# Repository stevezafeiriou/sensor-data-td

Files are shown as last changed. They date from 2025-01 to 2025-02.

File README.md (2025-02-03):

# SensorDataTD: Real-Time Sensor Data Transfer System



The **SensorDataTD** project is a complete solution for real-time accelerometer data collection, processing, and transmission. It includes both hardware and software components, along with a 3D-printable case design.

You can find the complete tutorial at this link: [Sensor Data to TouchDesigner](#) _(Link to be added)_.

## Project Overview

This project comprises four main components:

1. **ESP32 Firmware**: Collects sensor data from an MPU6050 accelerometer, processes it, and transmits it via WebSocket.
2. **Server**: A Node.js WebSocket server to handle incoming sensor data and broadcast it to connected clients.
3. **React App**: A real-time 3D visualization of sensor data using React and Three.js.
4. **3D-Printed Case**: A custom enclosure for the LilyGo T-Display S3 and MPU6050 hardware.

## Folder Structure

- **`SensorDataTD/`**
  - **`SensorDataTD/`**: Contains the ESP32 firmware and related code.
    - [Read the ESP32 Firmware Documentation](./SensorDataTD/README.md)
  - **`models/`**: Contains `.stl` files and 3D-printing instructions for the project case.
  - **`server/`**: Contains the WebSocket server code in Node.js.
    - [Read the Server Documentation](./server/README.md)
  - **`react-app/`**: A React application for real-time visualization of sensor data.
    - [Read the React App Documentation](./react-app/README.md)
  - **`lilygo-t-display/`**: Contains Squareline Studio files for GUI design (ignored in Git).

## Project Setup

### 1. Hardware Setup

Components

#### Components Required:

- **LilyGo T-Display S3** or any other esp32 development board.
- **MPU6050 Accelerometer Module**
- **Vibration Motor**
- Jumper wires and breadboard or custom PCB
- Power supply (e.g., USB cable or LiPo battery)

#### Wiring Diagram:

Diagram

| LilyGo T-Display Pin | MPU6050 Pin | Vibration Motor Pin |
| --- | --- | --- |
| `3V3` | `VCC` | Positive terminal |
| `GND` | `GND` | Negative terminal |
| `GPIO18` | `SCL` | |
| `GPIO17` | `SDA` | |
| `GPIO10` | | Motor Positive Terminal |

**Note**: The TFT display is integrated into the LilyGo T-Display S3 board and requires no additional wiring or configuration.

### 2. ESP32 Firmware

1. **Set Up the Arduino IDE**:

   - Follow this guide to set up the LilyGo T-Display S3 in the Arduino IDE:  
     [LilyGo T-Display S3 - Setup Guide](https://stevezafeiriou.com/lilygo-t-display-s3-setup/)

   - Install the Required Libraries:
     - `TFT_eSPI` (pre-configured for the T-Display)
     - `WebSocketsClient`
     - `Preferences`
     - `Adafruit_MPU6050`

2. **Upload the Firmware**:

   - Open the `SensorDataTD/SensorDataTD.ino` file in Arduino IDE.
   - Select the **LilyGo T-Display S3** board under `Tools -> Board`.
   - Upload the firmware to the board.

3. **WiFi Configuration**:
   - On first boot, connect to the `SensorDataTD` WiFi network.
   - Navigate to `192.168.4.1` in your browser to configure WiFi and server IP.

[Read the ESP32 Firmware Documentation](./SensorDataTD/README.md)

### 3. Server Setup

1. **Install Node.js**:

   - Download and install Node.js from [https://nodejs.org/](https://nodejs.org/).

2. **Set Up the Server**:
   - Navigate to the `server/` directory:
     ```bash
     cd server
     ```
   - Install dependencies:
     ```bash
     npm install
     ```
   - Run the server:
     ```bash
     node server.js
     ```
   - The server will start on port `8080` and display your local IP addresses. Use one of these addresses to configure the ESP32 WebSocket connection.

[Read the Server Documentation](./server/README.md)

### 4. React App Setup

The React app provides a 3D visualization of the sensor data.

1. **Navigate to the React App Directory**:

   ```bash
   cd react-app
   ```

2. **Install Dependencies**:

   ```bash
   npm install
   ```

3. **Run the Development Server**:

   ```bash
   npm start
   ```

   Open [http://localhost:3000](http://localhost:3000) to view the app in your browser. The app will display real-time sensor data and update the rotation of a 3D model.

[Read the React App Documentation](./react-app/README.md)

### 5. 3D-Printed Case

1. **Print the Case**:

   - Use the `.stl` files in the `models/` folder to print the enclosure.
   - Recommended settings:
     - Material: PLA or PETG
     - Layer Height: 0.2mm
     - Infill: 20%-30%

2. **Assemble the Hardware**:
   - Place the LilyGo T-Display S3, MPU6050, and vibration motor into the case.
   - Use screws or adhesive as needed to secure the components.

## Usage

1. **Start the ESP32**:

   - Power on the LilyGo T-Display S3. It will connect to WiFi and start transmitting sensor data to the WebSocket server.

2. **Start the Server**:

   - Ensure the server is running and the LilyGo T-Display S3 is configured with the correct WebSocket server IP.

3. **Monitor the Data**:
   - Open the React app to visualize real-time 3D data updates.
   - Alternatively, connect a WebSocket client to the server (e.g., `ws://<server_ip>:8080`) to view the raw sensor data.

## Troubleshooting

1. **WiFi Issues**:

   - Check the SSID and password in the WiFi configuration portal.
   - Ensure the target network is available and within range.

2. **Server Not Receiving Data**:

   - Verify the LilyGo T-Display S3 is configured with the correct server IP.
   - Check that the Node.js server is running and listening on port 8080.

3. **React App Issues**:

   - Ensure the WebSocket URL in the `react-app/src/App.js` file is correctly configured to match the server's IP address.

4. **Accelerometer Data Issues**:

   - Ensure the MPU6050 is connected to the correct pins (`SCL -> GPIO18`, `SDA -> GPIO17`).
   - Verify that the MPU6050 module is powered.

5. **Vibration Motor Not Working**:
   - Check the wiring for the motor (`Input -> GPIO10`).
   - Verify that the vibration threshold is configured appropriately in the firmware.

## TO DO LIST

1. **FOR ESP32**:

   - Add DEEP SLEEP mode to save power OR add a switch.
   - Include OTA functionality, in order to program the device wirelessly.

2. **FOR MODELS**:

   - Include specific positions and clips to attach the components + the LilyGo.
   - Maybe include an ON-OFF switch.

## License

This project is licensed under the MIT License. See the [LICENSE](LICENSE) file for details.

## Contributions

Contributions are welcome! Feel free to submit issues, feature requests, or pull requests.

## Contact

For questions or support, please contact [steve@saphirelabs.com](mailto:steve@saphirelabs.com).

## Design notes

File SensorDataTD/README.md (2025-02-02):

# Sensor Data Transmission System

This project is an ESP32-based system that collects sensor data from an MPU6050 module, processes it, and transmits it in real-time via a WebSocket server. The system also includes dual WiFi configuration capabilities (AP + STA mode) and provides visual feedback using the **LilyGo T-Display S3**.

## Features

- **MPU6050 Accelerometer & Gyroscope Integration:**  
  Reads and processes both 3-axis acceleration and 3-axis gyro data.

- **Dual Transmission Modes:**:

  - **MODE A**: Always shows all sensor data (acceleration and gyro) plus the current button state on the TFT display.
  - **MODE B**:
    - **Display**: Updates the TFT display with sensor data only when the button is pressed; otherwise, it displays a “Press Button” message.
    - **WebSocket**: Sends sensor data only when the button is pressed.

- **Real-Time WebSocket Transmission:**  
  Transmits sensor data in JSON format to a specified WebSocket server.

- **WiFi Manager (AP + STA mode):**
  Enables WiFi configuration via a web portal. The device operates as both an Access Point (AP) for configuration and as a Station (STA) to connect to your network.

- **Integrated TFT Display:**  
  The LilyGo T-Display S3’s built-in TFT display provides real-time feedback on WiFi status, sensor readings (acceleration and gyro), and button state.

- **Vibration Detection & Feedback:**  
  A vibration motor is activated when the accelerometer detects significant movement (exceeding a configurable threshold).

## Prerequisites

### Hardware

- **LilyGo T-Display S3**
  - Integrated ESP32-S3 and TFT display.
- **MPU6050 Module**
  - Provides both accelerometer and gyroscope data.
- **Push Button & LED**
  - The button is used for mode switching and triggering display/transmission in MODE B.
  - The LED indicates the button state.
- **Vibration Motor (Optional)**
  - For haptic feedback based on movement detection.

### Software

- **Arduino IDE**
- **Required Libraries**:
  - `TFT_eSPI` (for the built-in TFT display)
  - `WebSocketsClient` (for WebSocket communication)
  - `Preferences` (for persistent storage)
  - `Adafruit_MPU6050` (for sensor support)
  - `Wire` (for I2C communication)

### LilyGo T-Display S3 Setup Guide

Follow the guide below to configure the LilyGo T-Display S3 in the Arduino IDE:  
[**LilyGo T-Display S3 - Setup Guide**](https://stevezafeiriou.com/lilygo-t-display-s3-setup/)

## Installation

1. **Clone or Download the Repository:**

   ```bash
   git clone <repository_url>
   cd <repository_folder>
   ```

2. **Open the Project Files in the Arduino IDE:**

   - `SensorDataTD.ino`
   - `MPU6050Sensor.h` / `MPU6050Sensor.cpp`
   - `Vibration.h` / `Vibration.cpp`
   - `WifiManager.h` / `WifiManager.cpp`

3. **Configure the Arduino IDE for the LilyGo T-Display S3**  
   Follow the [setup guide](https://stevezafeiriou.com/lilygo-t-display-s3-setup/) to install the necessary board definitions and libraries.

4. **Upload the Code**  
   Use the Arduino IDE to compile and upload the code to the LilyGo T-Display S3.

## Usage

### System Initialization

1. **Power On:**

   - The TFT display powers up and shows a calibration message.
   - The MPU6050 module undergoes a 3-second calibration (for both acceleration and gyro).

2. **WiFi Configuration:**

   - If no saved WiFi credentials are available, the device starts in Access Point (AP) mode.
   - Connect to the `SensorDataTD` WiFi network (default password: `12345678`).
   - Open your browser and navigate to `192.168.4.1`.
   - Enter your WiFi SSID, password, and WebSocket server IP address in the provided portal.
   - The device will attempt to connect to your network (STA mode) while still hosting the AP for configuration.

### Data Transmission & Display Modes

- **MODE A (Default Mode):**
  - **TFT Display:**  
    Continuously displays all sensor data (3-axis acceleration and 3-axis gyro) along with the current button state.
  - **WebSocket Transmission:**  
    Sends all sensor data in JSON format (including a computed acceleration magnitude and button state) continuously.
- **MODE B:**

  - **TFT Display:**  
    Displays sensor data only when the button is pressed; otherwise, a “Press Button” message is shown.
  - **WebSocket Transmission:**  
    Transmits sensor data only when the button is pressed.

  **Switching Modes:**

  - Double-press the button (two presses within one second) to toggle between MODE A and MODE B.

### Data Format

The sensor data transmitted via WebSocket is sent as a JSON object. For example, in MODE A the JSON data may look like:

```json
{
	"ax": 1.23,
	"ay": 4.56,
	"az": 7.89,
	"gx": 0.12,
	"gy": 0.34,
	"gz": 0.56,
	"acc": 8.9,
	"btn": 1
}
```

In MODE B, data is transmitted only when the button is pressed and does not include the button state.

### Integrated TFT Display

- **Information Shown:**
  - **WiFi Status:** (Connected or the AP IP if not connected)
  - **Mode:** (MODE A or MODE B)
  - **Sensor Data:**
    - Acceleration values (X, Y, Z)
    - Gyroscope values (X, Y, Z)
  - **Button State:** Displayed in MODE A; in MODE B, data is shown only when the button is pressed.

### Vibration Feedback

- The vibration motor is activated when the acceleration on any axis exceeds the defined threshold (`1.65g` by default).
- This threshold can be modified in the source code if needed.

## Code Overview

### SensorDataTD.ino

- **Initialization:**  
  Sets up the TFT display, MPU6050, button, LED, and vibration motor.
- **Main Loop:**
  - Reads sensor data (acceleration and gyro).
  - Applies filtering and processes data.
  - Updates the TFT display based on the current mode.
  - Sends data over WebSocket according to the active mode.
  - Handles button press detection and mode switching.
  - Runs the WiFi manager (AP + STA mode) and web server for configuration.

### MPU6050Sensor.h / MPU6050Sensor.cpp

- **Functionality:**  
  Initializes the MPU6050, performs calibration, and reads both accelerometer and gyroscope data.
- **Data Processing:**  
  Applies a low-pass filter to smooth the sensor data.

### Vibration.h / Vibration.cpp

- **Functionality:**  
  Controls the vibration motor. The motor activates when the sensor data indicates significant movement.

### WifiManager.h / WifiManager.cpp

- **Functionality:**  
  Manages WiFi connections and credentials.
- **Dual Mode Operation:**  
  Configures the ESP32 to operate in both Access Point (AP) and Station (STA) modes.
- **Web Portal:**  
  Provides a web portal for entering WiFi credentials and the WebSocket server IP.

## Configuration

### Vibration Threshold

You can modify the vibration threshold in the `SensorDataTD.ino` file:

```cpp
#define VIBRATION_THRESHOLD 1.65
```

### WebSocket Server

Set the WebSocket server IP address via the web portal. Alternatively, you can predefine it in the code:

```cpp
String ws_server = "192.168.1.100";
initializeWebSocket(ws_server);
```

## Troubleshooting

1. **WiFi Issues:**

   - Verify the entered SSID and password in the web portal.
   - Ensure the target WiFi network is available and within range.
   - Check that the device is in STA mode (if credentials are saved) or connect via AP mode for configuration.

2. **WebSocket Communication:**

   - Confirm the correct WebSocket server IP address.
   - Ensure the WebSocket server is running and accessible.

3. **Sensor Data Problems:**

   - Ensure the MPU6050 module is connected to the correct pins (`SDA -> GPIO17`, `SCL -> GPIO18`).
   - Verify proper power connections to the sensor module.

4. **Vibration Feedback:**
   - Check the wiring of the vibration motor (input pin, e.g., GPIO10, and ground).
   - Adjust the threshold value if the motor is triggering too frequently or not at all.

## Future Improvements

- Implement secure WebSocket (WSS) for encrypted data transmission.
- Add OTA (Over-The-Air) update functionality.
- Enhance error handling for WiFi and sensor operations.
- Expand sensor support to include additional environmental parameters.

## License

This project is licensed under the MIT License. See the [LICENSE](LICENSE) file for details.

## Contributions

Contributions are welcome! Please submit issues or pull requests to help improve this project.

## Contact

For questions or support, please contact [steve@saphirelabs.com](mailto:steve@saphirelabs.com).

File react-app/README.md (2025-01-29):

# Sensor Data Visualization with React and Three.js

This project is a 3D visualization of real-time sensor data from an ESP32 device, developed using **React** and **Three.js**. The application features a rotating 3D model with a shiny chrome material, controlled dynamically by sensor data streamed via WebSocket.

## Features

- Real-time sensor data visualization.
- Rotating 3D model rendered with `@react-three/fiber` and `@react-three/drei`.
- Shiny chrome material effect on the 3D model.
- Responsive UI with styled-components.
- Easily configurable WebSocket connection for sensor data.

## Getting Started

Follow these steps to set up and run the application locally.

### Prerequisites

Make sure you have the following installed:

- Node.js (>=16.x)
- npm (>=8.x)

### Installation

1. Clone this repository:

   ```bash
   git clone https://github.com/your-username/your-repo.git
   cd your-repo
   ```

2. Install the required dependencies:

   ```bash
   npm install
   ```

### Configuration

1. Update the WebSocket URL in `App.js` to match your ESP32 server's IP address and port:

   ```javascript
   const ws = new WebSocket("http://<your-nodejs-server-ip>:8080");
   ```

2. Ensure your ESP32 device is configured to send sensor data in JSON format, with `x`, `y`, and `z` fields representing rotation angles in degrees.

### Usage

Run the app in development mode:

```bash
npm start
```

Open [http://localhost:3000](http://localhost:3000) to view it in your browser. The app will automatically reload if you make changes to the code.

### Production Build

To create a production-ready build:

```bash
npm run build
```

The build files will be generated in the `build` directory. You can deploy these files to any static hosting service.

### File Structure

```
src/
├── App.js                # Main application file
├── components/
│   ├── Scene.js          # 3D visualization component
│   ├── SceneElements.js  # Styled-components for the scene container
├── index.js              # Entry point of the application
└── App.css               # Global styles
```

## How It Works

### Real-Time Data

- The app connects to an ESP32 WebSocket server to receive real-time sensor data.
- Sensor data is parsed and used to update the rotation of the 3D model.

### 3D Visualization

- The 3D model is rendered using `@react-three/fiber` and `@react-three/drei`.
- A shiny chrome effect is applied using a `MeshStandardMaterial` with high metalness and low roughness.

### UI

- The application includes a simple card UI displaying sensor data, styled with `styled-components`.

## License

This project is licensed under the MIT License. See the [LICENSE](LICENSE) file for details.

## Acknowledgments

- Thanks to the creators of [React](https://reactjs.org/) and [Three.js](https://threejs.org/) for providing amazing tools for developers.
- Special thanks to the developers of `@react-three/fiber` and `@react-three/drei` for making 3D rendering in React simple and intuitive.

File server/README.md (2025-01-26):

# Sensor Data WebSocket Server

This project implements a WebSocket server for handling real-time sensor data. It listens for incoming connections, receives sensor data in JSON format, and broadcasts it to all connected clients.

## Features

- **WebSocket Support**: Clients can connect to the server using WebSockets.
- **Real-Time Data Broadcasting**: Sensor data received from one client is broadcast to all connected clients.
- **Local IP Detection**: Displays the local IP addresses for easy connection.
- **Error Handling**: Handles invalid JSON messages gracefully.

## Prerequisites

Ensure the following software is installed on your system:

1. **Node.js** (v14 or higher)  
   You can download Node.js from [https://nodejs.org/](https://nodejs.org/).

2. **WebSocket Client** (optional for testing)  
   You can use tools like [websocat](https://github.com/vi/websocat), browser-based WebSocket clients, or custom scripts to connect to the server.

## Installation

1. Clone this repository:

   ```bash
   git clone <repository_url>
   cd <repository_folder>
   ```

2. Install the required dependencies:
   ```bash
   npm install
   ```

## Usage

### Start the Server

Run the server with the following command:

```bash
node server.js
```

### Server Output

When the server starts, it will display the local IP addresses and the listening port:

```
Server running at:
- http://<local_IP_1>:8080
- http://<local_IP_2>:8080
```

Replace `<local_IP_1>` and `<local_IP_2>` with the actual local IP addresses displayed in the output.

### Connecting a Client

Clients can connect to the WebSocket server using the following URL:

```
ws://<server_IP>:8080
```

### Sending Sensor Data

Clients can send JSON-formatted sensor data to the server. Example message format:

```json
{
	"temperature": 22.5,
	"humidity": 65
}
```

The server will broadcast this data to all connected clients.

## Code Overview

### Key Functions

1. **`getLocalIP()`**  
   Retrieves the local IPv4 addresses of the machine running the server.

2. **HTTP Server**  
   Serves a basic text response when accessed via a web browser or HTTP client:

   ```
   Sensor Data WebSocket Server
   ```

3. **WebSocket Server**

   - Listens for incoming WebSocket connections.
   - Processes incoming messages:
     - Parses and logs sensor data.
     - Broadcasts data to all connected clients.
   - Handles errors for invalid JSON messages.

4. **Error Logging**  
   Logs the raw message and error details if a message fails to parse.

## Development

### Dependencies

- **WebSocket**: Provides WebSocket server functionality.  
  Install with:
  ```bash
  npm install ws
  ```
- **HTTP**: Built-in Node.js module for handling HTTP requests.
- **OS**: Built-in Node.js module for accessing network interfaces.

### Extending Functionality

To extend the server, you can:

- Add custom validation for sensor data.
- Implement authentication for secure client connections.
- Log data to a database or file system.

## Troubleshooting

1. **Port Already in Use**  
   If port `8080` is occupied, modify the `server.listen` call in `server.js` to use a different port:

   ```javascript
   server.listen(9090, () => {
       ...
   });
   ```

2. **Invalid JSON Messages**  
   If a client sends malformed JSON, the server logs the raw message and an error:
   ```
   Error processing message: SyntaxError: Unexpected token ...
   Raw message that failed: <message>
   ```

## License

This project is licensed under the MIT License. See the [LICENSE](LICENSE) file for details.

## Contributions

Contributions are welcome! Feel free to submit issues, feature requests, or pull requests.

## Contact

For questions or support, please contact [steve@saphirelabs.com](mailto:steve@saphirelabs.com).

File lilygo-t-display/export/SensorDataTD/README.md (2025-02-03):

# User Interface for m+ (ESP32 + MPU6050 Motion Capture)

This project provides a full-featured user interface (UI) for the m+ motion capture system based on an ESP32 and MPU6050. The UI is built using LVGL (Light and Versatile Graphics Library) and is designed to run on the **LilyGo T-Display S3 - ESP32S3 development board**. It features dual screens, a calibration indicator, sensor data display (with one decimal place), mode switching (MODE A and MODE B), and integration with a WiFi Manager that supports both Access Point (AP) and Station (STA) modes.

## Features

- **LVGL-Based UI with Dual Screens:**

  - **Main Screen (ui_main):** Displays sensor data (acceleration and gyro) along with the current WiFi status, mode, and button state.
  - **Press Button Screen (ui_pressButton):** Shown in MODE B when the button is not pressed (prompting the user to press the button to view sensor data).

- **Sensor Data Display:**

  - Reads 3-axis acceleration and 3-axis gyro data from the MPU6050.
  - Values are formatted to one decimal (e.g., 0.0) for clarity.

- **Calibration Indicator:**

  - A dedicated UI element (ui_isCallibrated) shows the calibration status.
  - **During calibration:** It displays a dark green color (hex: `0x006C07`).
  - **After calibration:** It updates to an intense green color (hex: `0x00FF00`).

- **Mode Switching & LED Animations:**

  - **MODE A:** The main screen is always displayed.
  - **MODE B:** The main screen is shown only while the external button is pressed; otherwise, a "Press Button" screen is displayed.
  - A double-press on the external button (GPIO3) toggles between modes.
  - LED animations indicate mode changes (1 blink for MODE A, 2 blinks for MODE B), and the LED follows the button state.

- **WiFi Manager (AP + STA):**

  - Uses the ESP32’s dual-mode capability so that the device creates an Access Point for configuration while also attempting to connect to a saved WiFi network.
  - The integrated web server (via WifiManager.h/cpp) handles WiFi credential configuration and firmware updates.

- **Vibration Feedback:**
  - The system activates a vibration motor when significant motion is detected (based on a configurable threshold).

## Get Started

1. **Environment Setup:**

   - Follow the [LilyGo T-Display S3 Setup Guide](https://stevezafeiriou.com/lilygo-t-display-s3-setup/) to configure the Arduino IDE for the LilyGo T-Display S3 board.
   - Make sure to set up the `TFT_eSPI` library correctly. (No modifications to the library are needed if you follow the guide.)

2. **Open the Project:**

   - Open the `ui.ino` file (this UI version) in Arduino.
   - Ensure your Sketchbook location (via **File > Preferences**) is set to the path of this UI project.

3. **Library and Board Selection:**

   - Verify that all required libraries (LVGL, TFT_eSPI, WebSocketsClient, Preferences, etc.) are installed.
   - Select the appropriate board (LilyGo T-Display S3 / ESP32S3).

4. **Build and Upload:**
   - Build and upload the project to your board.

## Important Notes

- This UI version is tailored for the **LilyGo T-Display S3 - ESP32S3 development board**. You can purchase it from [LilyGo](https://www.lilygo.cc/CjcAky) (affiliate link).
- The UI uses LVGL and was generated with SquareLine Studio. Two screens are used:
  - **Main Screen (ui_main):** Displays sensor data, WiFi status, mode, and button state.
  - **Press Button Screen (ui_pressButton):** Displays a message prompting the user to press the button (used in MODE B when the button is not pressed).
- **Calibration:**  
  The MPU6050 sensor undergoes a 3-second calibration on startup. During calibration, the calibration indicator shows dark green; afterward, it updates to intense green.
- **Mode Switching:**  
  A double press of the external button (GPIO3) toggles between MODE A (always showing sensor data) and MODE B (showing sensor data only when the button is pressed).
- **WiFi Manager:**  
  The project operates in AP + STA mode, enabling configuration via a web portal while attempting to connect to a saved WiFi network.
- **No Touchpad Support:**  
  This project does not include a touchpad driver. If you need touch input, you must add a compatible library and driver.

## LCD Driver & Touchpad Comparison Table

(See the original documentation for a comparison of supported drivers. This project is tested with the built-in TFT display of the LilyGo T-Display S3.)

## Deployment

Once you have built and uploaded the project, your device will:

- Boot up and initialize the sensor (performing calibration).
- Start in AP mode if no WiFi credentials are saved.
- Allow configuration of WiFi and WebSocket server through the web portal.
- Display sensor data on the UI according to the selected mode.
- Use LED animations to indicate mode changes.

## Troubleshooting

- **Calibration Indicator:**  
  If the calibration indicator does not maintain the intense green color after calibration, ensure that the UI update function is not continuously overwriting its style. (In this project, the style is forced to refresh only when needed.)
- **WiFi/AP Issues:**  
  Make sure that `server.handleClient()` is being called in the loop (this is necessary for the WiFi Manager to work properly).
- **LVGL UI Issues:**  
  Verify that your SquareLine Studio–generated UI files (ui.h, ui.c) are in the correct location and that LVGL is initialized properly.

This project is now ready for deployment on your **LilyGo T-Display S3 - ESP32S3** development board!

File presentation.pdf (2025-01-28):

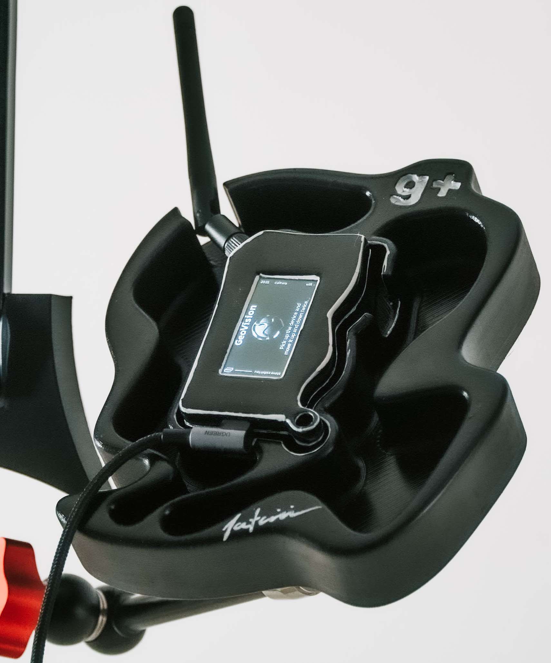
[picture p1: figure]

# SENSOR DATA TRANSFER

V1.0

STEVE ZAFEIRIOU

www.stevezafeiriou.com Copyright © 2025 Saphire Labs. All rights reserved.

MICROCONTROLLERS IN ART (AND BEYOND)

# Hardware Architecture Overview

Page 03

## Core Components

01

# A Powerful Motion Sensor Hub

You’ll learn how to capture dynamic motion, provide tactile
vibrations, and wirelessly relay information to a Node.js server—
opening a world of possibilities for immersive experiences in art,
interactive installation, or/and IoT applications. | Page 05

## System Diagram

STEVE ZAFEIRIOU | SAPHIRE LABS | SENSOR DATA TRANSMITION

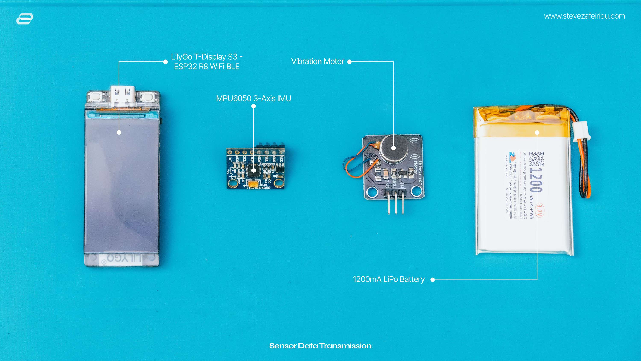
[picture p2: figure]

# 1.1 Core Components

STEVE ZAFEIRIOU | SENSOR DATA TRANSMITION

003

# 1.1 Core Components

## LilyGo T-Display S3 ESP32:

Dual-core 240MHz Xtensa LX6 processor Integrated 1.9” IPS TFT display (170x320 resolution)
Built-in lithium battery management
8MB PSRAM + 16MB Flash memory

## MPU6050 6-DoF IMU

3-axis accelerometer (±4g range) 3-axis gyroscope (±500°/sec)
I²C interface (17/18 pins for SDA/SCL)

## Vibration Motor

Eccentric rotating mass (ERM) type Digital Control via GPIO10
3.3V logic compatible

## LilyGo T-Display Setup Guide: www.stevezafeiriou.com/lilygo-t-display-s3-setup

004

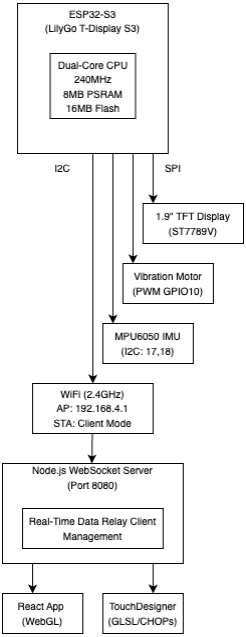
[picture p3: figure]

1. The ESP32 coordinates everything, reading sensor data from the MPU6050 over I²C.
2. The vibration motor is driven using a PWM signal for haptic feedback.
3. The TFT display is updated via SPI to show real-time readings or status messages.

## 4. Finally, the Wi-Fi interface allows the ESP32 to transmit motion data to a Node.js

server and onward to client applications like React or TouchDesigner.

# 1.2 System Block Diagram

005

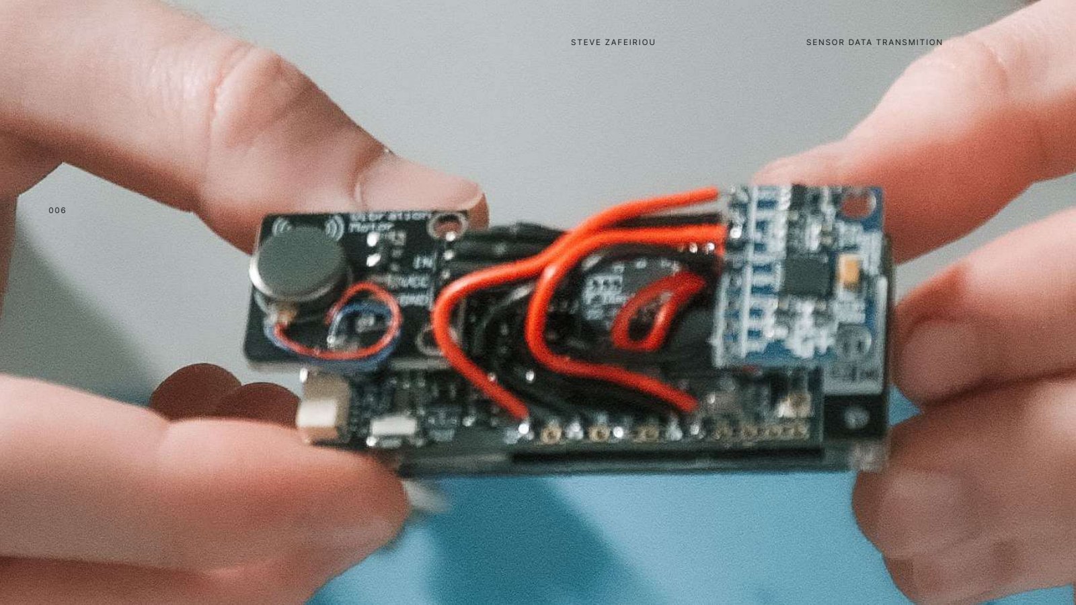
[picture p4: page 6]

006

# Core Firmware

Page 08

## Sensor Processing

02

# Programming the LilyGo T-Display S3 - ESP32 using the Arduino IDE

Page 09

## Haptic Feedback

STEVE ZAFEIRIOU | SAPHIRE LABS | SENSOR DATA TRANSMITION

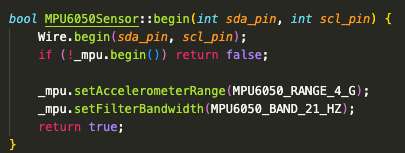
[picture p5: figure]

# 2.1 Sensor Processing Pipeline

## In the file MPU6050Sensor.cpp, we have these key features:

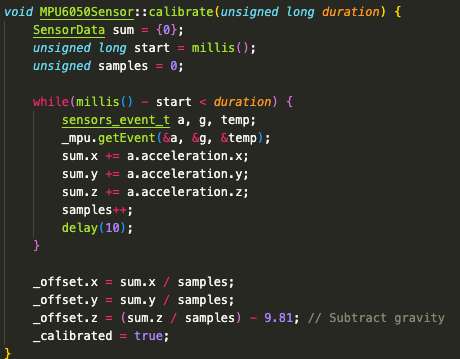
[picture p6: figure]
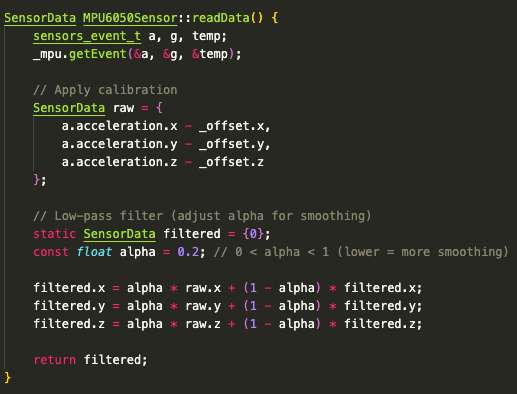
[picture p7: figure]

Hardware Abstraction | Calibration Logic | Signal Filtering
008

# 2.2 Haptic Feedback System

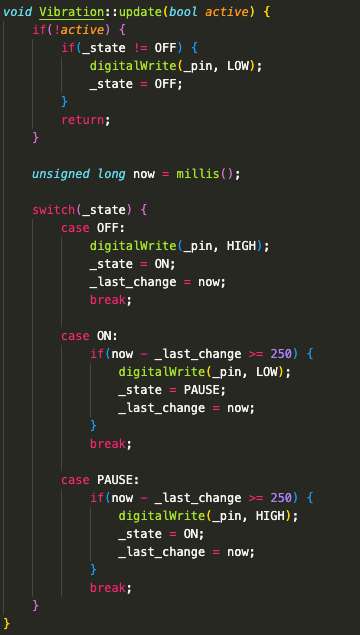
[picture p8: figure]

1. OFF state waits for a trigger, such as sensor input indicating the user wants feedback.

## 2. ON state is 250 milliseconds of activation, driving the motor via PWM at a certain

duty cycle.

3. PAUSE is 250 milliseconds of rest, after which it cycles back to ON if feedback is still required.

This creates a 2Hz pulsating effect that feels stronger and more noticeable to users compared to continuous vibration.
The short pause also helps in reducing power consumption by about 50%.

009

# Network Communication Stack

Page 11

## Dual-Mode WiFi

03

Soft Access Pont,

# Station Mode & Websockets

Page 13

## WebSocket Implementation

STEVE ZAFEIRIOU | SAPHIRE LABS | SENSOR DATA TRANSMITION

# 3.1 Dual-Mode WiFi Architecture

## Connection Workflow:

1. Starts in AP+STA mode
simultaneously
2. Serves configuration portal at 192.168.4.1
3. Attempts stored credential connection
4. Maintains AP while connected as STA

## This dual-mode approach (Access Point + Station) is especially handy in development or public installations, where you want both a stable local network connection and a

fallback direct access point for debugging or firmware updates.

011

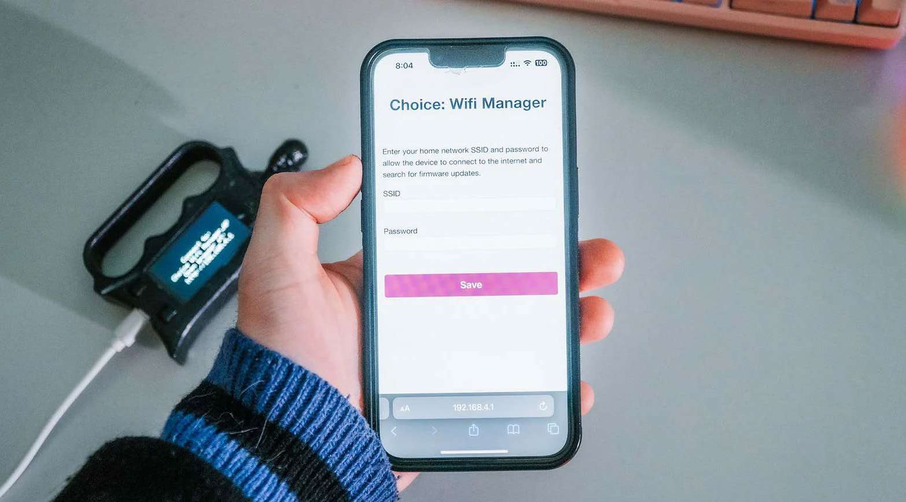
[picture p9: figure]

012

# 3.2 WebSocket Implementation

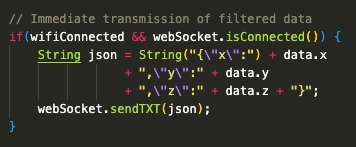
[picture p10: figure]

Initialize Websockets | Data Transmission

## Optimization: JSON packaging instead of binary reduces client-side parsing complexity at the cost of 23% larger payload (measured 48 bytes vs 37 bytes

binary).

013

# Server Infrastructure

Page 15

## Node.js Relay Server

04

# A Node.js application to receive incoming WebSocket messages

STEVE ZAFEIRIOU | SAPHIRE LABS | SENSOR DATA TRANSMITION

# 4.1 Node.js Relay Server

Initialize Websockets | Broadcast to All Clients | Network Discovery

015

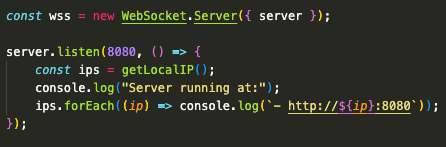
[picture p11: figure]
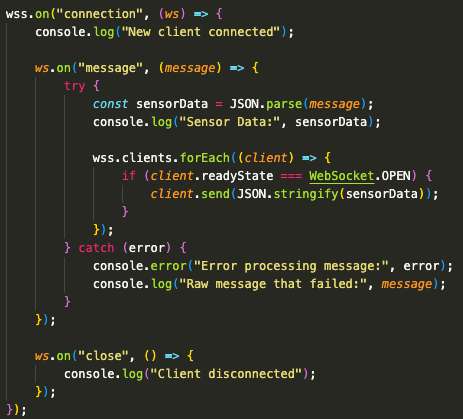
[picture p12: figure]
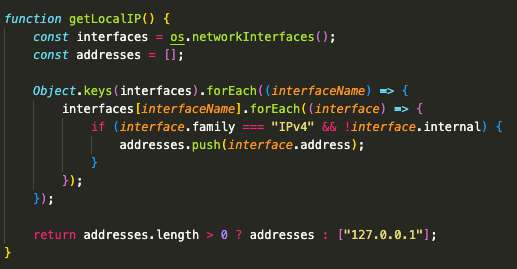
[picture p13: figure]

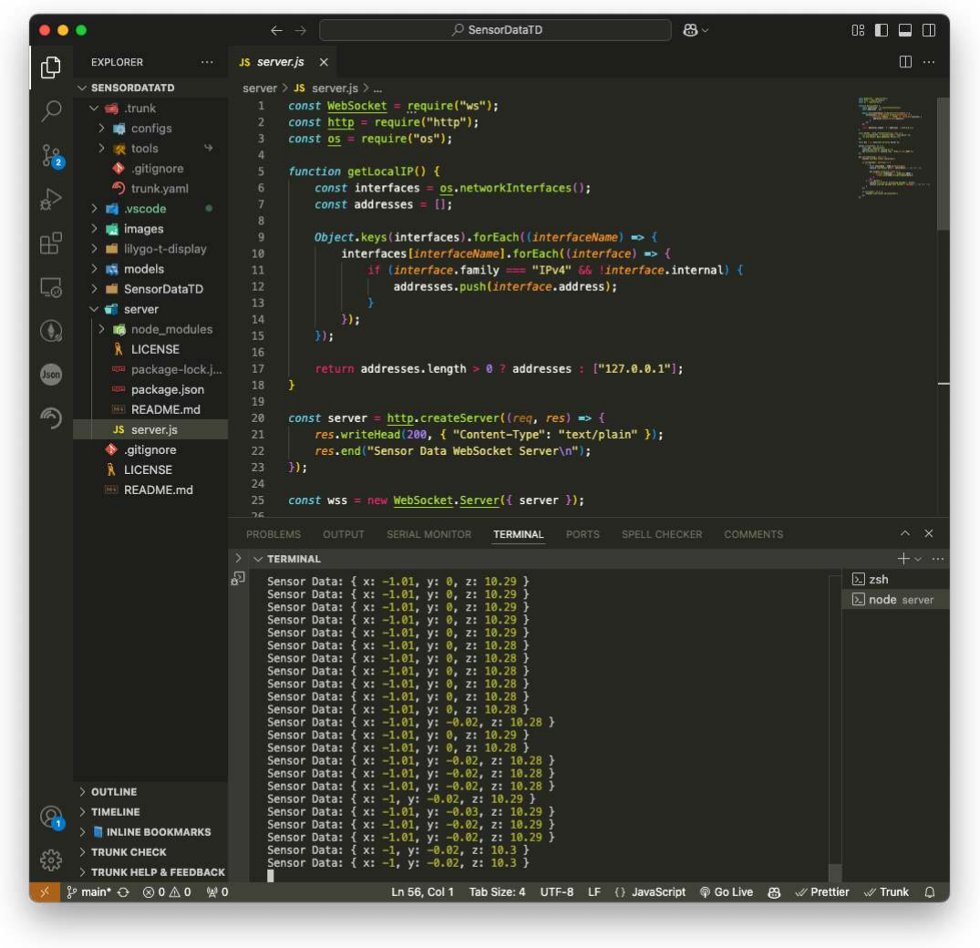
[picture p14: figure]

## 1. The server receives sensor data from the LilyGo

T-Display S3 - ESP32 microcontroller.

## 2. It then iterates through all connected WebSocket

clients and relays the data in JSON format.

## 3. The server has a network discovery function to automatically figure out your server’s local IP address

and simplify the device configuration process.

016

# Client Integration Patterns

Page 18

## TouchDesigner

05

# Connecting clients to

the Relay server. | Page 19
| React / Web App
STEVE ZAFEIRIOU | SAPHIRE LABS | SENSOR DATA TRANSMITION

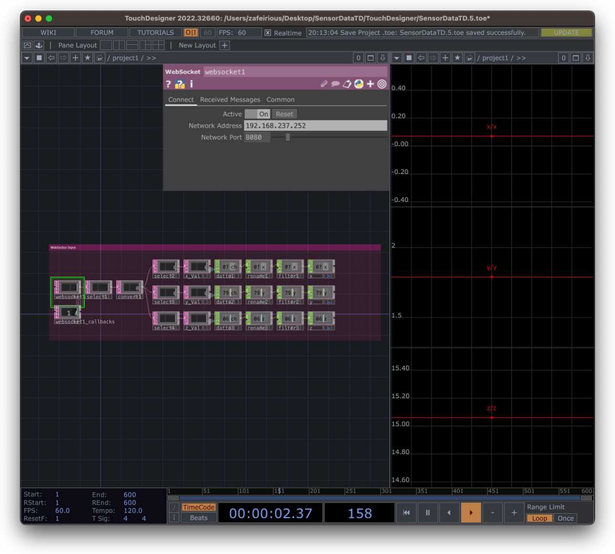
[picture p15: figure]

# 5.1 TouchDesigner Data Handling

## TouchDesigner is a great platform for real-time visual and

interactive media applications.

1. Raw sensor data (e.g., x/y/z accelerometer values) is received via WebSocket.
2. Data is routed through Select DAT operators to isolate specific axes.
3. Filter CHOP cleans the data for stability.
4. Final CHOP nulls (x, y, z) are the parameters that can be used to control visuals (e.g., shaders, animations).

018

# 5.2 React Visualization

Initialize Websockets

## Use a WebSocket hook that allows React components to subscribe to incoming sensor

data.

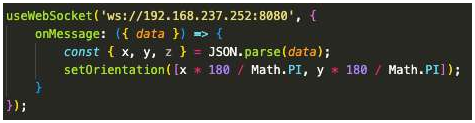
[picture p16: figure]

React is a widely utilized JavaScript library designed for developing user interfaces.
Applications created with React are recognized for their interactivity, responsiveness, and efficiency.
This is achieved through the use of components—modular and reusable units of UI—and the virtual DOM, which ensures that only the necessary portions of the interface are updated when changes occur.
React is particularly prominent in the development of single-page applications (SPAs), enabling dynamic content updates without the need for a full page reload.
The library is maintained by Meta (previously Facebook) and supported by a robust open-source community.

019

# Advanced Optimization Techniques

Page 21

## Power Management

06

Power efficiency and,

# data filtering is crucial for portable or long-

term installations.

Page 22

## Data Filtering

STEVE ZAFEIRIOU | SAPHIRE LABS | SENSOR DATA TRANSMITION

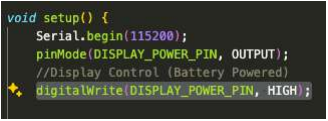
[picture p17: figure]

# 6.1 Power Management

Display Control

## Many TFT displays have a pin to control the backlight. Turning it off when the

display isn’t in use can significantly reduce power consumption.

Power efficiency is crucial for portable or long-term installations. There are two primary strategies: Display Control & Wifi Power Saving (that we didn’t implemented on this project)

021

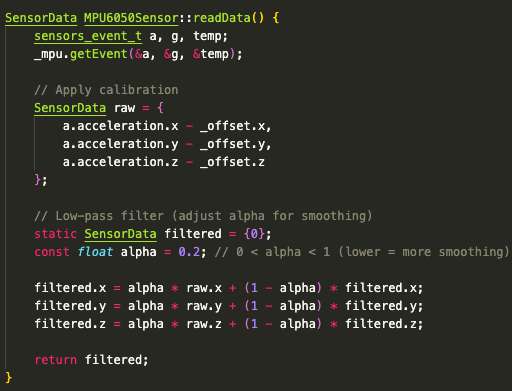
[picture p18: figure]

# 6.2 Data Filtering

Low-Pass Filter
The MPU6050 alone can provide raw accelerometer and gyroscope data,

## we often use low-pass exponential moving average filter for more accurate orientation

The filter blends new raw data with historical filtered data, creating a smoothed output that dampens sudden spikes while preserving general trends.

Time | Step | Raw Value (X) Filtered Value (X)
0
1
2

1.0
2.0
1.5
0.2 | * | 1.0 | = | 0.2
0.22.0 | + | 0.80.2 | = | 0.56
0.21.5 + 0.80.56 = 0.748

022

# Troubleshooting Guide

Page 24

## Common Issues

07

# Common issues and their Solutions

STEVE ZAFEIRIOU | SAPHIRE LABS | SENSOR DATA TRANSMITION

Symptom | Diagnostic Steps | Possible Solutions
No WebSocket Connect | 1. Check if server IP is correct in Preferences 2. Verify device is on the same network. | Ensure firewall and router allow port 8080
Drifting IMU Values | 1. Re-calibrate on a truly flat surface 2. Reduce electromagnetic interference sources | Re-run calibration and relocate sensor away from EMI
Intermittent Vibration | 1. Measure GPIO10 with an oscilloscope 2. Check that the PWM signal is stable and not clipping Add a flyback diode or small resistor if | needed
Display Artifacts | 1. Verify TFT_eSPI board configuration 2. Ensure the backlight pin is receiving stable voltage | Double-check power supply lines and wiring

# 7.1 Common Issues

024

Thank you.

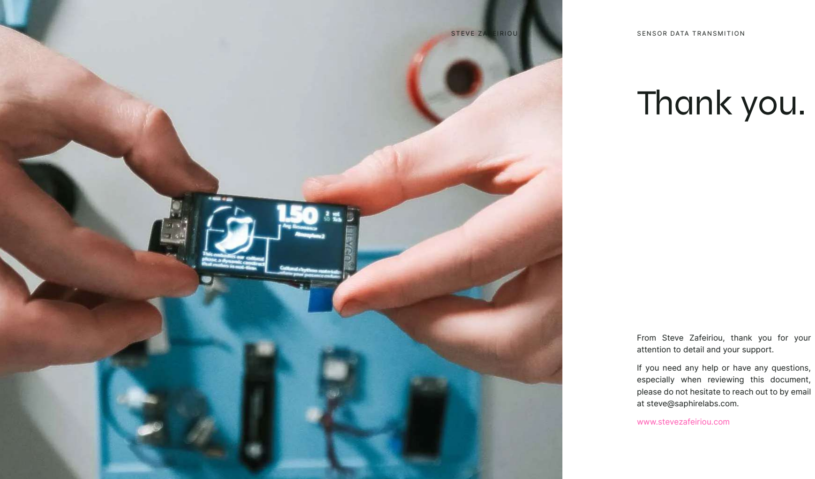
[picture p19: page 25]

From Steve Zafeiriou, thank you for your attention to detail and your support.
If you need any help or have any questions, especially when reviewing this document, please do not hesitate to reach out to by email at steve@saphirelabs.com.
www.stevezafeiriou.com

025

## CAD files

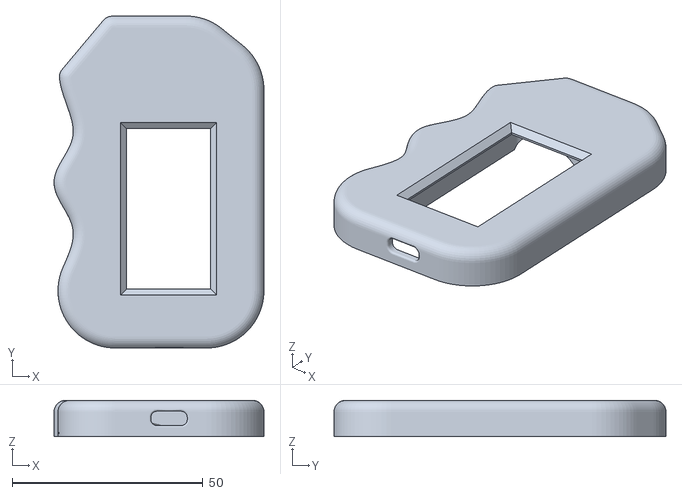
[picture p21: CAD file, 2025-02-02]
models/case_top_v4.stl
55.0 x 87.0 x 9.50

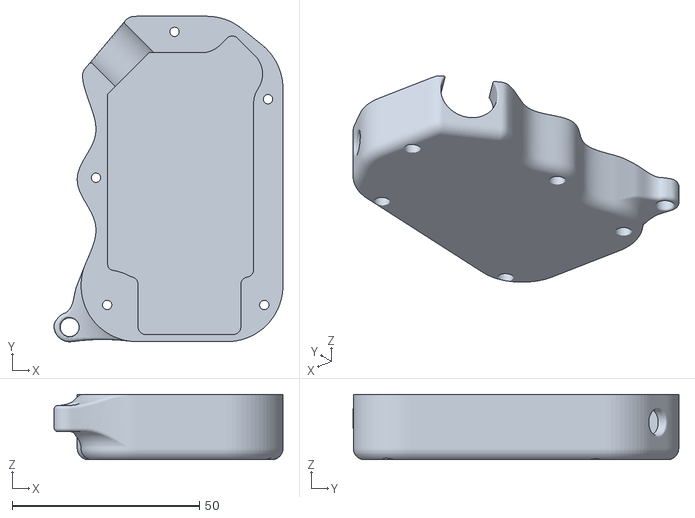
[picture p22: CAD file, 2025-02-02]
models/case_bottom_v4.stl
61.2 x 87.0 x 17.5

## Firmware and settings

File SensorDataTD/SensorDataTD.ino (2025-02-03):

#include <Arduino.h>
#include <TFT_eSPI.h>
#include <WebSocketsClient.h>
#include <Preferences.h>
#include <WiFi.h>
#include "MPU6050Sensor.h"
#include "Vibration.h"
#include "WifiManager.h"

// --------------------------------------------------------------------
// Hardware Definitions
// --------------------------------------------------------------------
#define DISPLAY_POWER_PIN 15
#define VIBRATION_THRESHOLD 1.65  // Vibration threshold

// Hardware definitions for push button and LED
#define BUTTON_PIN 3   // push button pin (using INPUT_PULLUP)
#define LED_PIN    2   // LED pin

TFT_eSPI tft = TFT_eSPI();
WebSocketsClient webSocket;

// --------------------------------------------------------------------
// WiFi Manager Variables
// --------------------------------------------------------------------
Preferences preferences;
bool wifiConnected = false;
String ws_server = "";

// --------------------------------------------------------------------
// Timing variables for sensor & display
// --------------------------------------------------------------------
unsigned long last_data = 0;
unsigned long last_display = 0;
const int DATA_INTERVAL = 20;  // 50Hz data collection

// --------------------------------------------------------------------
// Vibration control
// --------------------------------------------------------------------
bool vibration_active = false;

// --------------------------------------------------------------------
// Device Mode Definitions and Global Variables
// --------------------------------------------------------------------
enum DeviceMode { MODE_A, MODE_B };
DeviceMode currentMode = MODE_A;  // initial mode

// For button double-press detection:
unsigned long lastButtonPressTime = 0;
int buttonPressCount = 0;
bool buttonStateLast = false;  // previous state (for edge detection)

// --------------------------------------------------------------------
// LED Animation Variables (for mode change)
// --------------------------------------------------------------------
bool modeAnimationActive = false;
unsigned long modeAnimationStart = 0;
int modeAnimationBlinkCount = 0;  // 1 for MODE A, 2 for MODE B
unsigned long lastLEDToggleTime = 0;
bool ledAnimationState = false;

// --------------------------------------------------------------------
// Helper: Convert mode enum to string for display
// --------------------------------------------------------------------
const char* modeToString(DeviceMode mode) {
  return (mode == MODE_A) ? "MODE A" : "MODE B";
}

// --------------------------------------------------------------------
// WebSocket Initialization
// --------------------------------------------------------------------
void initializeWebSocket(String serverIP) {
    ws_server = serverIP;
    webSocket.begin(serverIP, 8080, "/");
    webSocket.setReconnectInterval(5000);
}

// --------------------------------------------------------------------
// Display Update Function
//    Displays sensor data (acceleration and gyro) and the button state.
// --------------------------------------------------------------------
void updateDisplay(const SensorData &data, const String& status, bool btnState) {
    tft.fillScreen(TFT_BLACK);
    tft.setTextColor(TFT_WHITE);
    
    // Top header with WiFi and mode
    tft.setTextSize(1);
    tft.setCursor(0, 0);
    tft.printf("WiFi: %s\nMode: %s", status.c_str(), modeToString(currentMode));
    
    // Sensor data (Acceleration)
    tft.setTextSize(1);
    tft.setCursor(0, 30);
    tft.printf("Acc:\nX:%.2f\nY:%.2f\nZ:%.2f", data.ax, data.ay, data.az);
    
    // Sensor data (Gyro)
    tft.setCursor(0, 80);
    tft.printf("Gyro:\nX:%.2f\nY:%.2f\nZ:%.2f", data.gx, data.gy, data.gz);
    
    // Button state display
    tft.setCursor(0, 110);
    tft.printf("Button: %s", btnState ? "Pressed" : "Not Pressed");
}

// --------------------------------------------------------------------
// Setup Function
// --------------------------------------------------------------------
void setup() {
    Serial.begin(115200);
    pinMode(DISPLAY_POWER_PIN, OUTPUT);
    digitalWrite(DISPLAY_POWER_PIN, HIGH); // Power the display

    // Initialize button and LED pins.
    pinMode(BUTTON_PIN, INPUT_PULLUP);
    pinMode(LED_PIN, OUTPUT);
    digitalWrite(LED_PIN, LOW);
    
    // Initialize modules
    Vibration::begin(10);
    tft.init();
    tft.setRotation(3);
    
    if (!MPU6050Sensor::begin(17, 18)) {
        tft.println("MPU6050 Error!");
        while(1);
    }

    tft.println("Calibrating...");
    MPU6050Sensor::calibrate(); // Calibrate for 3 seconds
    tft.fillScreen(TFT_BLACK);

    // Start WiFi Manager
    startWiFiManager();
    preferences.begin("wifi_config", true);
    ws_server = preferences.getString("server_ip", "");
    preferences.end();
    
    if (wifiConnected && !ws_server.isEmpty()) {
        initializeWebSocket(ws_server);
    }
}

// --------------------------------------------------------------------
// Main Loop
// --------------------------------------------------------------------
void loop() {
    unsigned long currentMillis = millis();

    // Run non-blocking services
    webSocket.loop();
    server.handleClient();
    Vibration::update(vibration_active);

    // -------------------------------
    // Read Button State
    // -------------------------------
    // With INPUT_PULLUP, unpressed reads HIGH and pressed reads LOW.
    bool isPressed = (digitalRead(BUTTON_PIN) == LOW);
    
    // -------------------------------
    // Button Double-Press Detection to Toggle Modes
    // -------------------------------
    if (!buttonStateLast && isPressed) {  // edge detection: not pressed -> pressed
        if (currentMillis - lastButtonPressTime < 600) {
            buttonPressCount++;
        } else {
            buttonPressCount = 1;
        }
        lastButtonPressTime = currentMillis;
    }
    buttonStateLast = isPressed;
    
    if (buttonPressCount == 2) {
        // Toggle between MODE_A and MODE_B
        currentMode = (currentMode == MODE_A) ? MODE_B : MODE_A;
        buttonPressCount = 0;  // reset the counter
        
        // Start LED mode animation:
        modeAnimationActive = true;
        modeAnimationStart = currentMillis;
        lastLEDToggleTime = currentMillis;
        ledAnimationState = false;
        // Set blink count: 1 for MODE A, 2 for MODE B.
        modeAnimationBlinkCount = (currentMode == MODE_A) ? 1 : 2;
    }
    if (currentMillis - lastButtonPressTime > 600) {
        buttonPressCount = 0;
    }
    
    // -------------------------------
    // LED Update / Animation
    // -------------------------------
    if (modeAnimationActive) {
        if (currentMillis - modeAnimationStart < 1000) {
            // Compute the half-period: (1 second) divided by (number of on/off toggles)
            unsigned long period = 1000UL / (modeAnimationBlinkCount * 2);
            if (currentMillis - lastLEDToggleTime >= period) {
                ledAnimationState = !ledAnimationState;
                digitalWrite(LED_PIN, ledAnimationState ? HIGH : LOW);
                lastLEDToggleTime = currentMillis;
            }
        } else {
            modeAnimationActive = false;
            // After the animation ends, update LED normally according to button state.
            digitalWrite(LED_PIN, isPressed ? HIGH : LOW);
        }
    } else {
        // Normal LED update (reflect the button state).
        digitalWrite(LED_PIN, isPressed ? HIGH : LOW);
    }
    
    // -------------------------------
    // Sensor Data Collection (50Hz)
    // -------------------------------
    if (currentMillis - last_data >= DATA_INTERVAL) {
        SensorData data = MPU6050Sensor::readData();
        last_data = currentMillis;

        // Apply a deadzone to acceleration data.
        const float DEADZONE = 0.02;
        if (fabs(data.ax) < DEADZONE) data.ax = 0;
        if (fabs(data.ay) < DEADZONE) data.ay = 0;
        if (fabs(data.az) < DEADZONE) data.az = 0;
        
        // Check vibration threshold (using acceleration).
        vibration_active = (fabs(data.ax) > VIBRATION_THRESHOLD);

        // Compute overall acceleration magnitude.
        float accMag = sqrt(data.ax * data.ax + data.ay * data.ay + data.az * data.az);

        // -------------------------------
        // WebSocket Data Transmission
        // -------------------------------
        // MODE A: Always send data.
        // MODE B: Send data only when the button is pressed.
        bool sendData = false;
        if (currentMode == MODE_A) {
            sendData = true;
        } else if (currentMode == MODE_B) {
            sendData = isPressed;
        }
        
        if (wifiConnected && webSocket.isConnected() && sendData) {
            String json = String("{\"ax\":") + String(data.ax, 2)
                        + ",\"ay\":" + String(data.ay, 2)
                        + ",\"az\":" + String(data.az, 2)
                        + ",\"gx\":" + String(data.gx, 2)
                        + ",\"gy\":" + String(data.gy, 2)
                        + ",\"gz\":" + String(data.gz, 2)
                        + ",\"acc\":" + String(accMag, 2);
            // Always include the button state in the JSON.
            int btnVal = isPressed ? 1 : 0;
            json += ",\"btn\":" + String(btnVal);
            json += "}";
            webSocket.sendTXT(json);
        }
        
        // -------------------------------
        // TFT Display Update
        // -------------------------------
        // MODE A: Always update display with sensor data and button state.
        // MODE B: Update display only when the button is pressed.
        if (currentMode == MODE_A) {
            String status = wifiConnected ? "Connected" : WiFi.softAPIP().toString();
            updateDisplay(data, status, isPressed);
        } else if (currentMode == MODE_B) {
            if (isPressed) {
                String status = wifiConnected ? "Connected" : WiFi.softAPIP().toString();
                updateDisplay(data, status, isPressed);
            } else {
                // Clear the display and show a waiting message.
                tft.fillScreen(TFT_BLACK);
                tft.setTextColor(TFT_WHITE);
                tft.setTextSize(2);
                tft.setCursor(0, 60);
                tft.println("Press Button");
            }
        }
        
        last_display = currentMillis;
    }
}

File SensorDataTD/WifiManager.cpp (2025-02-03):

#include "WifiManager.h"
#include <WiFi.h>
#include <Preferences.h>

// Define the server object
WebServer server(80); // Start the web server on port 80
extern Preferences preferences; // Ensure preferences is accessible
extern bool wifiConnected;
extern String ws_server;
extern void initializeWebSocket(String serverIP);

void startWiFiManager() {
    // Ensure WiFi is in the correct mode
    WiFi.mode(WIFI_AP_STA);  // Enable both Access Point (AP) and Station (STA)

    // Configure static IP for Soft AP
    IPAddress local_IP(192, 168, 4, 1);
    IPAddress gateway(192, 168, 4, 1);
    IPAddress subnet(255, 255, 255, 0);

    if (!WiFi.softAPConfig(local_IP, gateway, subnet)) {
        Serial.println("Soft AP Config failed!");
        return;
    }

    // Start the Soft AP with SSID and Password
    const char *ssid = "SensorDataTD";
    const char *password = "12345678";

    if (!WiFi.softAP(ssid, password)) {
        Serial.println("Failed to start Soft AP.");
        return;
    }

    // Print Soft AP IP
    Serial.print("Soft AP IP Address: ");
    Serial.println(WiFi.softAPIP());

    // Attempt Station connection
    preferences.begin("wifi_config", true);
    String savedSSID = preferences.getString("ssid", "");
    String savedPassword = preferences.getString("password", "");
    preferences.end();

    if (!savedSSID.isEmpty() && !savedPassword.isEmpty()) {
        WiFi.begin(savedSSID.c_str(), savedPassword.c_str());
        int counter = 0;

        while (WiFi.status() != WL_CONNECTED && counter < 30) {
            delay(1000);
            Serial.println("Attempting to connect as a Station...");
            counter++;
        }

        if (WiFi.status() == WL_CONNECTED) {
            wifiConnected = true;
        } else {
            wifiConnected = false;
            Serial.println("Failed to connect as a Station.");
        }
    }

    // Start the WebServer for AP configuration
    server.on("/", handlePortal);
    server.begin();
 
}

void handlePortal() {
    if (server.method() == HTTP_POST) {
        if (!server.hasArg("ssid") || !server.hasArg("password") || !server.hasArg("server_ip")) {
            server.send(400, "text/html", 
                "<!doctype html><html lang='en'><head>"
                "<meta charset='utf-8'><title>WiFi Manager</title>"
                "<meta name='viewport' content='width=device-width, initial-scale=1'>"
                "<style>"
                "*,::after,::before {box-sizing: border-box;}"
                "body {margin: 0; font-family: 'Segoe UI', Roboto, 'Helvetica Neue', Arial, 'Noto Sans', 'Liberation Sans';"
                "font-size: 1rem; font-weight: 400; line-height: 1.5; color: #212529; background-color: #f5f5f5;}"
                ".form-signin {width: 100%; max-width: 400px; padding: 15px; margin: auto;}"
                "h1, p {text-align: center;}"
                "</style></head><body>"
                "<main class='form-signin'>"
                "<h1>Error</h1><p>SSID, Password, and Server IP are required.</p>"
                "</main></body></html>");
            return;
        }
        
        String newSSID = server.arg("ssid");
        String newPassword = server.arg("password");
        String newServerIP = server.arg("server_ip");

        // Save credentials
        preferences.begin("wifi_config", false);
        preferences.putString("ssid", newSSID);
        preferences.putString("password", newPassword);
        preferences.putString("server_ip", newServerIP);
        preferences.end();

        WiFi.begin(newSSID.c_str(), newPassword.c_str());
        int counter = 0;
        while (WiFi.status() != WL_CONNECTED && counter < 30) {
            delay(1000);
            counter++;
        }
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

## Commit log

2025-02-02 Updated case, added Button, fixed TD
    [case_bottom.stl, case_bottom_v4.stl, case_top.stl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]
2025-02-03 led-animation on mode change
